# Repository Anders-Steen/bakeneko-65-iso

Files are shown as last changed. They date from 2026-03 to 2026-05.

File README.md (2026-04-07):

## ⚠️ Warning not finished ⚠️
I want to make my own ISO version of the Bakenko 65%.
Make it wireless.
[X] Decide on a ISO layout
[] ~ Replace daughterboard with mcu+interface ~
[X] Update PCB
[] ~ Update case ~ 

# Bakeneko 65 V4 - ISO

A simple 65% keyboard for DIYers. This project is a special homage to TGR x Singa UNIKORN 60 and OTD 356 Mini. See also the [introduction video](https://youtu.be/o677NcIUri4).

## Features

- Single piece tray case
- O-ring gasket mount (Friction fit)
- [Unified Daughterboard](https://github.com/ai03-2725/Unified-Daughterboard)
- ~QMK firmware and VIA~ ZMK
- PCB designed with KiCAD ~5.1.4~ 10.0

## Layout

Bakeneko 65 layouts

## Specs

- Dimensions: 315 x 110 x 30mm
- Front height: 18.5mm
- Home row height: 31mm(with GMK keycaps and bumpons)
- Typing angle: 6 degree
- Weight:
  - PLA Case: 390g
  - Aluminum Case: 760g
- O-ring gasket: VMQ-50(Silicone 50 duro) AS568-264
- MCU: NRF52840

## Notes
- Old files (v1) are no longer available. See [geekhack post](https://geekhack.org/index.php?topic=107316.msg2974824#msg2974824) for the context
- The use of old (v1) mounting posts is prohibited
- All files are to be used at your own risk
- As for stabilizers, only PCB snap ins are supported

## Resources

- Documents: https://drive.google.com/drive/folders/1tddSihOS8Pgf1lTQOjHohYCl8efxXIeH
  - Parts guide and other useful information
  - Will be added and updated as needed
- Discord: https://discord.gg/fMY96TeEwV
  - Have fun with community members
  - Talk about Bakeneko builds and mods, and share your works
  - You can also contact me from there

## Special thanks to

- **Elaine** for [Unikorn](https://geekhack.org/index.php?topic=98587.50). Allowed me to publish the Unikorn-inspired case as open source and encouraged me
- Of course, I also show my respect and gratitude to **yuktsi**
- **coarse** for PCB review and kind support. His great work has refined the PCB well

## Also I should mention

- **OTD** for 356 Mini. Origin of O-ring gasket mount style
- **Evy** for [Plain60 series](https://github.com/evyd13/plain60-c). I used it as a reference for my PCB design. They also answered my miscellaneous questions
- **ai03** for [MX_Alps_Hybrid](https://github.com/ai03-2725/MX_Alps_Hybrid). Also got a lot of help from his discord server
- **overset** for [JP01](https://github.com/overset/JP01). The idea of publishing the case design on Onshape. After seeing their great work I switched from fusion360 to Onshape
- **Rhuk** gave me a lot of advice on keyboard design and manufacturing
- **Maker Keyboards** suggested adding a plate cutout to remove the PCB using a keycap puller
- And many community members for giving me advice and feedback, thanks!

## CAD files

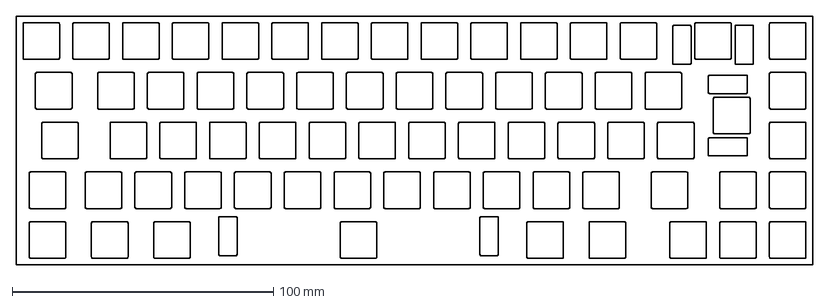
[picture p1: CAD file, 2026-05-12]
plate/fr4/plate-2026-04-13T18_37_32.604Z.dxf
304.8 x 95.2 mm

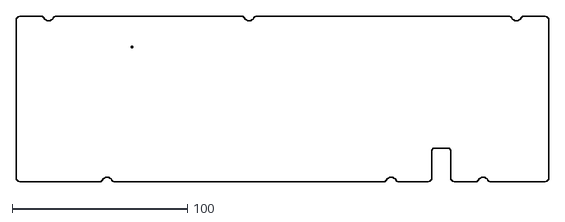
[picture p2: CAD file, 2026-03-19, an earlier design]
pcb_old/pcb-outline.dxf
303.8 x 94.2

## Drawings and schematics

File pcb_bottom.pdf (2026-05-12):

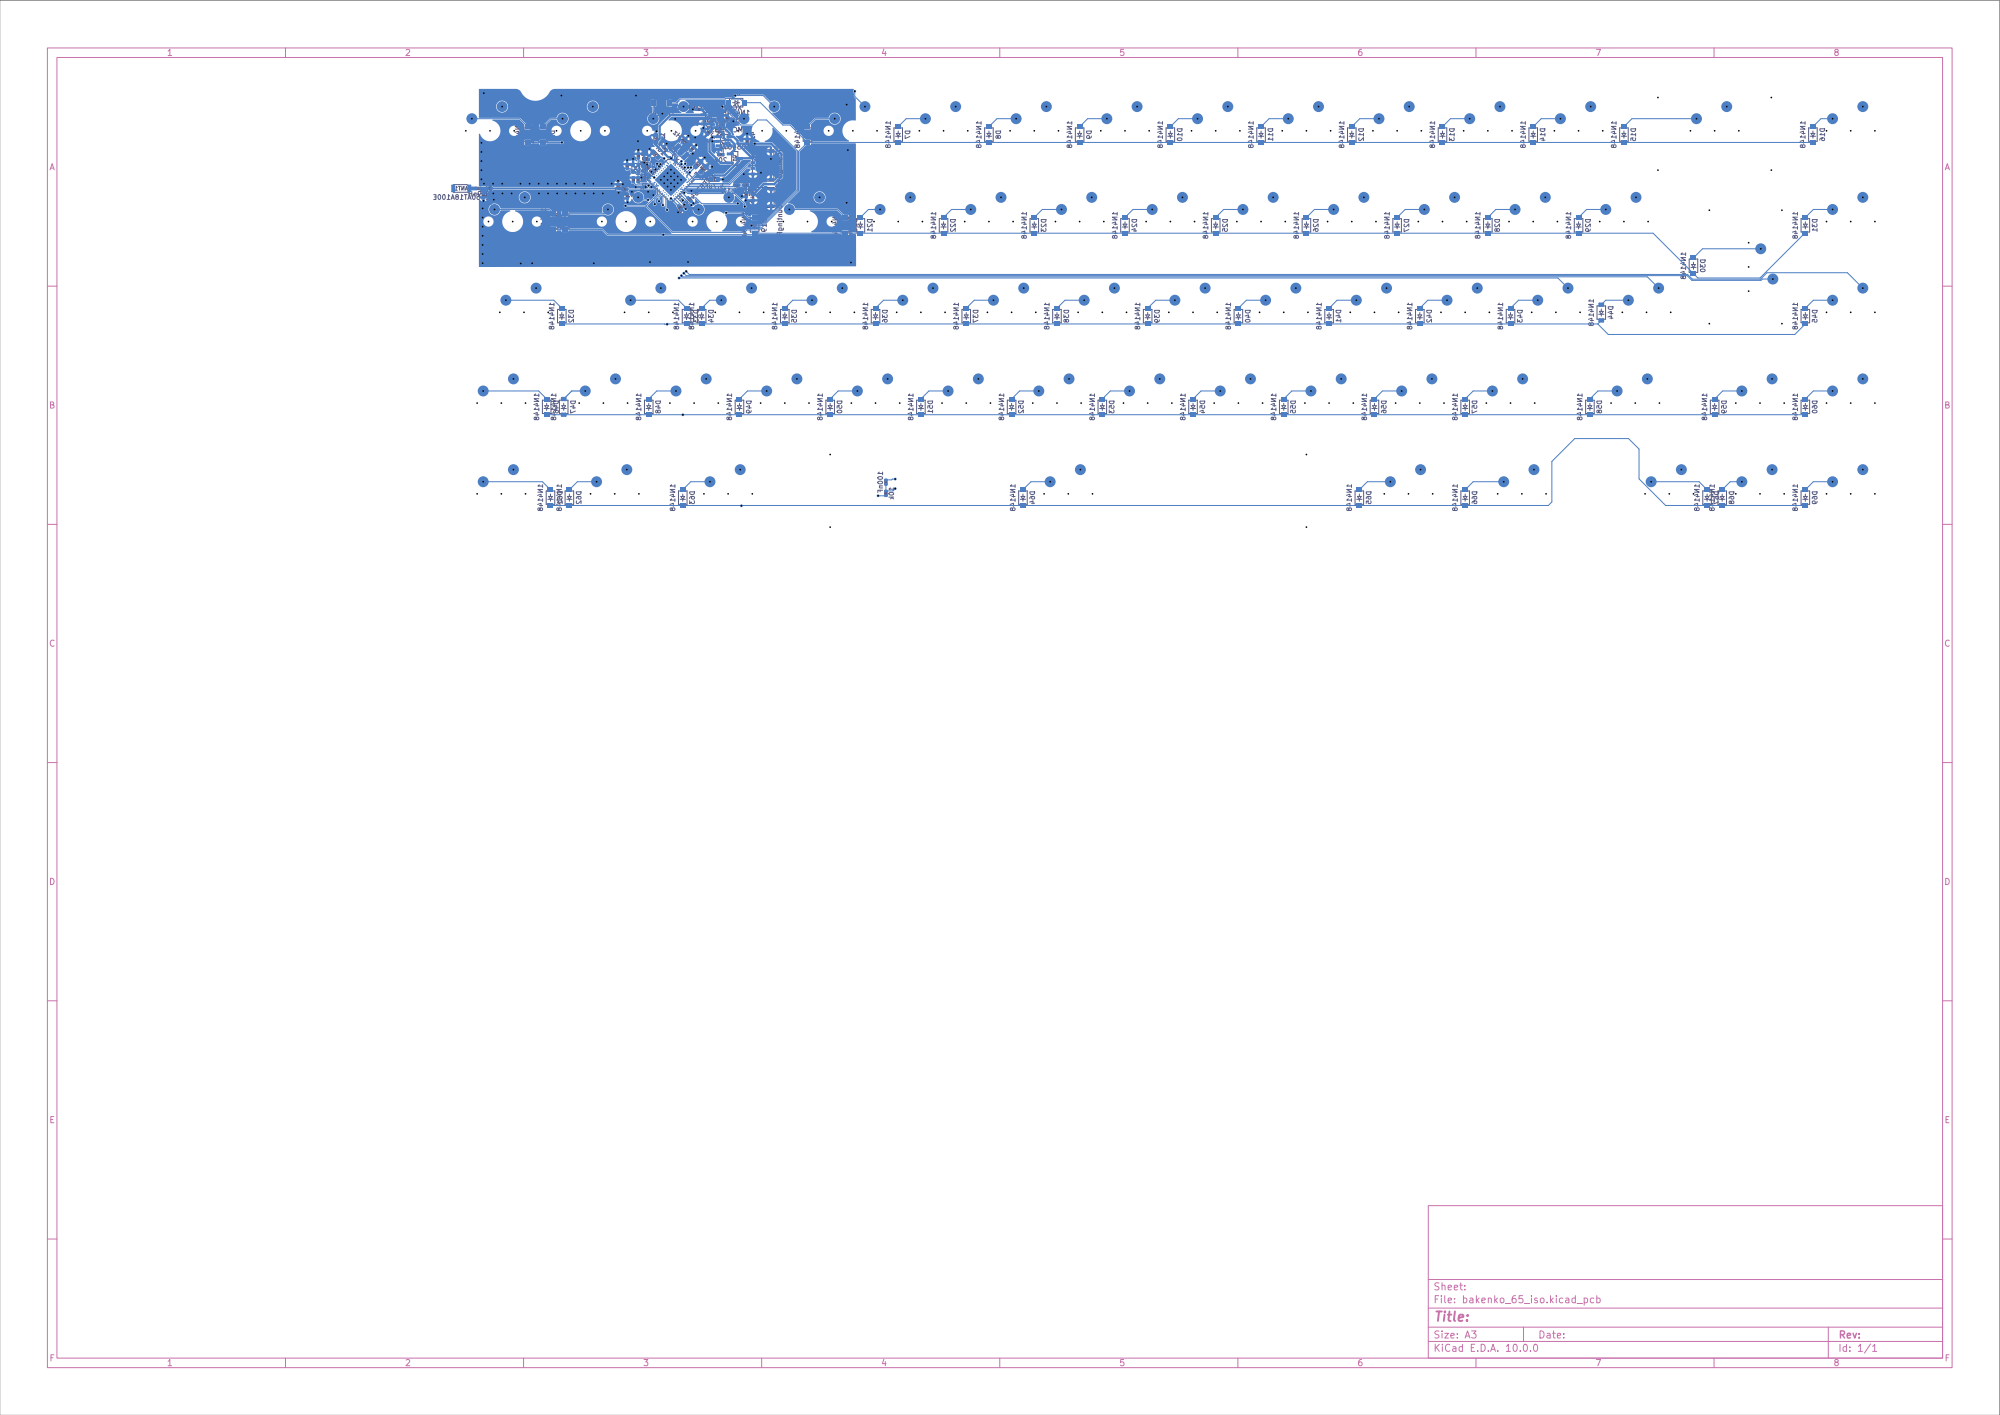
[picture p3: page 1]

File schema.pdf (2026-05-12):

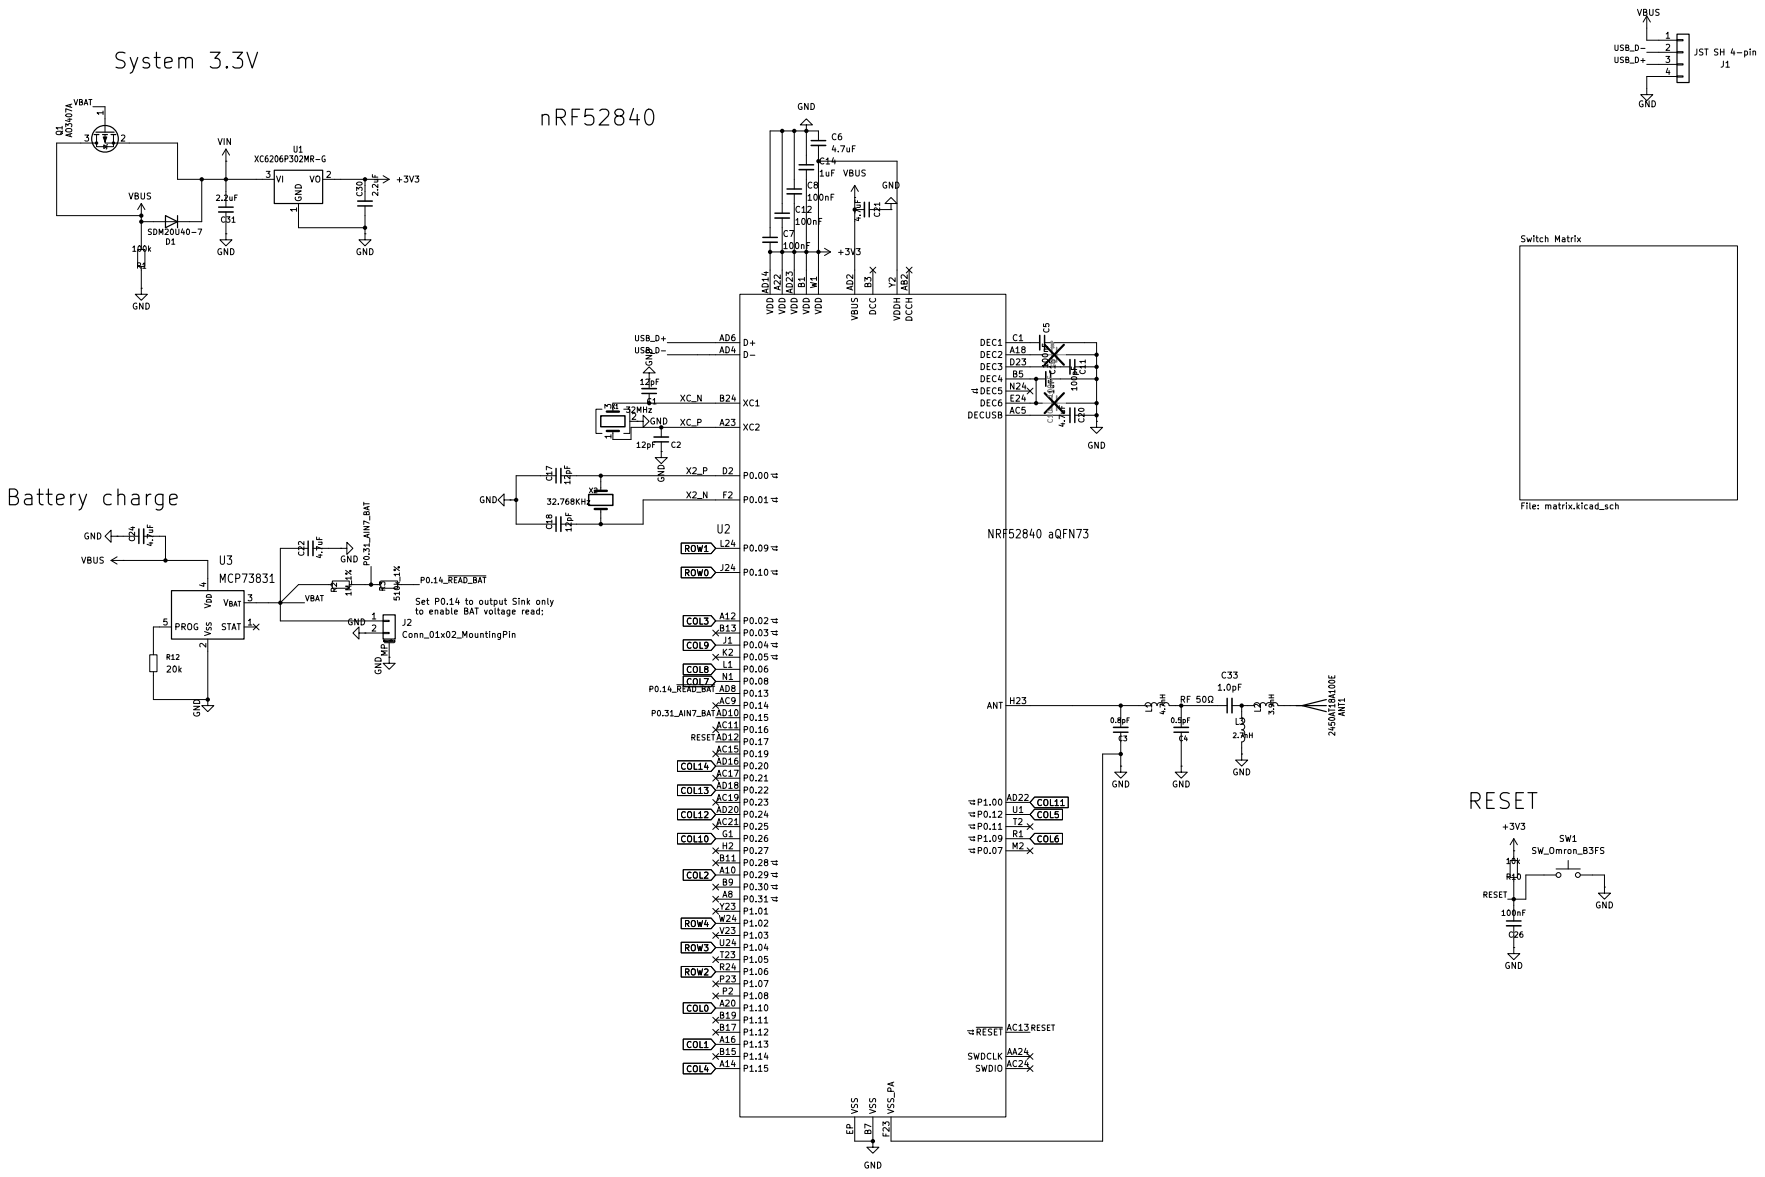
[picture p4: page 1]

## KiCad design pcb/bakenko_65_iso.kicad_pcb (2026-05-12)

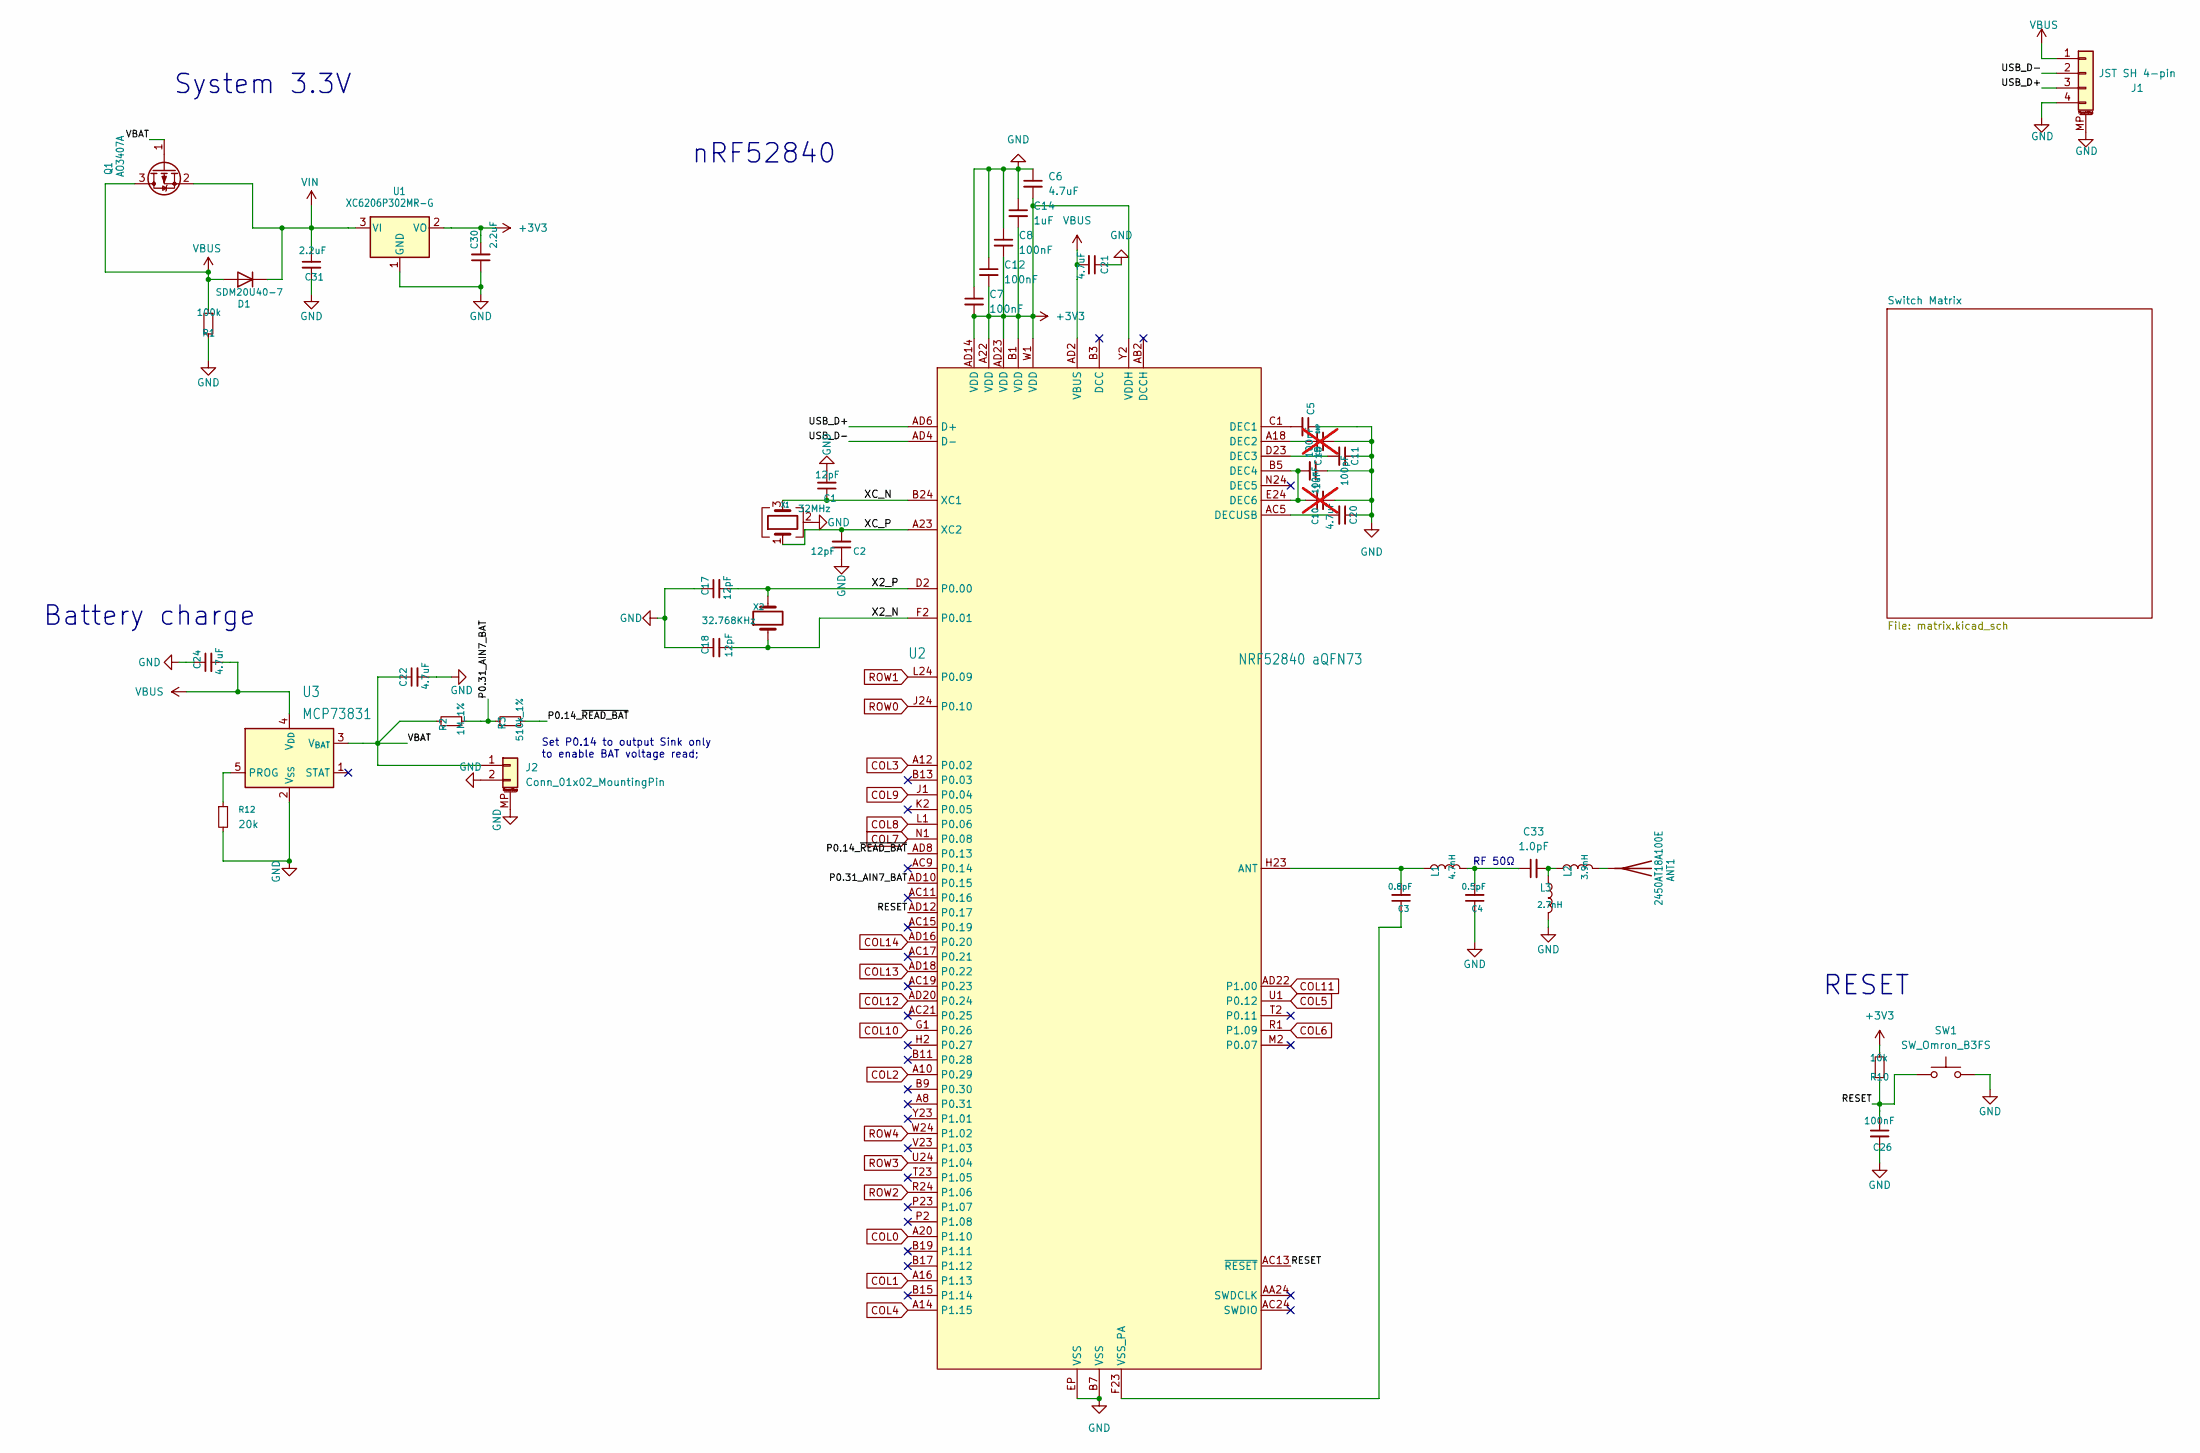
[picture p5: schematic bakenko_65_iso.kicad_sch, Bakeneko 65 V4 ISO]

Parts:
ANT1: 2450AT18A100E; Johanson_2450AT18x100_2400-2500Mhz
C1, C2, C17, C18: 12pF; C_0402_1005Metric
C3: 0.8pF; C_0402_1005Metric
C4: 0.5pF; C_0402_1005Metric
C5, C7, C8, C12, C26: 100nF; C_0402_1005Metric
C6, C20, C21: 4.7uF; C_0603_1608Metric
C10: 100nF; C_0402_1005Metric; not fitted
C11: 100pF; C_0402_1005Metric
C13: DNP; C_0402_1005Metric; not fitted
C14, C15: 1uF; C_0603_1608Metric
C22, C24: 4.7uF; C_0402_1005Metric
C30, C31: 2.2uF; C_0402_1005Metric
C33: 1.0pF; C_0402_1005Metric
D1: SDM20U40-7; D_SOD-523
J1: JST SH 4-pin; Molex_Pico-EZmate_78171-0004_1x04-1MP_P1.20mm_Vertical; LCSC Part # C160404
J2: Conn_01x02_MountingPin; Molex_Pico-EZmate_78171-0002_1x02-1MP_P1.20mm_Vertical
L1: 4.7nH; L_0402_1005Metric
L2: 3.9nH; L_0402_1005Metric
L3: 2.7nH; L_0402_1005Metric
Q1: AO3407A; SOT-23
R1: 100k; R_0402_1005Metric
R2: 1M_1%; R_0402_1005Metric
R3: 510k_1%; R_0402_1005Metric
R10: 10k; R_0402_1005Metric
R12: 20k; R_0402_1005Metric
SW1: SW_Omron_B3FS; SW_SPST_TS-1088-xR020
U1: XC6206P302MR-G; SOT-23
U2: NRF52840 aQFN73; Nordic_AQFN-73-1EP_7x7mm_P0.5mm
U3: MCP73831; SOT-23-5; MPN BQ25101YFPT
X1: 32MHz; Crystal_SMD_2016-4Pin_2.0x1.6mm
X2: 32.768KHz; Crystal_SMD_3215-2Pin_3.2x1.5mm

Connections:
+3V3: C6.2, C7.2, C8.2, C12.2, C14.2, C30.2, R10.2, U1.2 (VO), U2.A22 (VDD), U2.AD14 (VDD), U2.AD23 (VDD), U2.B1 (VDD), U2.W1 (VDD), U2.Y2 (VDDH)
/P0.14_~READ_BAT: R3.2, U2.AD8 (P0.13)
/P0.31_AIN7_BAT: R2.2, R3.1, U2.AD10 (P0.15)
/RESET: C26.1, R10.1, SW1.1, U2.AC13 (~RESET), U2.AD12 (P0.17)
/USB_D+: J1.3, U2.AD6 (D+)
/USB_D-: J1.2, U2.AD4 (D-)
/VBAT: C22.1, J2.1, Q1.1 (G), R2.1, U3.3 (V_{BAT})
/X2_N: C18.2, U2.F2 (P0.01), X2.1
/X2_P: C17.2, U2.D2 (P0.00), X2.2
/XC_N: C1.1, U2.B24 (XC1), X1.3
/XC_P: C2.2, U2.A23 (XC2), X1.1
COL0: U2.A20 (P1.10); also elsewhere on the board
COL1: U2.A16 (P1.13); also elsewhere on the board
COL2: U2.A10 (P0.29); also elsewhere on the board
COL3: U2.A12 (P0.02); also elsewhere on the board
COL4: U2.A14 (P1.15); also elsewhere on the board
COL5: U2.U1 (P0.12); also elsewhere on the board
COL6: U2.R1 (P1.09); also elsewhere on the board
COL7: U2.N1 (P0.08); also elsewhere on the board
COL8: U2.L1 (P0.06); also elsewhere on the board
COL9: U2.J1 (P0.04); also elsewhere on the board
COL10: U2.G1 (P0.26); also elsewhere on the board
COL11: U2.AD22 (P1.00); also elsewhere on the board
COL12: U2.AD20 (P0.24); also elsewhere on the board
COL13: U2.AD18 (P0.22); also elsewhere on the board
COL14: U2.AD16 (P0.20); also elsewhere on the board
GND: C1.2, C2.1, C4.1, C5.1, C6.1, C7.1, C8.1, C10.2, C11.1, C12.1, C13.2, C14.1, C15.1, C17.1, C18.1, C20.1, C21.1, C22.2, C24.1, C26.2, C30.1, C31.2, J1.4, J1.MP (MountPin), J2.2, J2.MP (MountPin), L3.2, R1.2, R12.2, SW1.2, U1.1 (GND), U2.B7 (VSS), U2.EP (VSS), U3.2 (V_{SS}), X1.2 (G), X1.4 (G)
unnamed: ANT1.1 (A_1), L2.2
unnamed: C4.2, C33.1, L1.2
unnamed: C33.2, L2.1, L3.1
unnamed: C3.2, L1.1, U2.H23 (ANT)
unnamed: C5.2, U2.C1 (DEC1)
unnamed: C13.1, U2.A18 (DEC2)
unnamed: C11.2, U2.D23 (DEC3)
unnamed: C10.1, C15.2, U2.B5 (DEC4), U2.E24 (DEC6)
unnamed: C20.2, U2.AC5 (DECUSB)
unnamed: C3.1, U2.F23 (VSS_PA)
unnamed: R12.1, U3.5 (PROG)
ROW0: U2.J24 (P0.10); also elsewhere on the board
ROW1: U2.L24 (P0.09); also elsewhere on the board
ROW2: U2.R24 (P1.06); also elsewhere on the board
ROW3: U2.U24 (P1.04); also elsewhere on the board
ROW4: U2.W24 (P1.02); also elsewhere on the board
VBUS: C21.2, C24.2, D1.2 (A), J1.1, Q1.3 (D), R1.1, U2.AD2 (VBUS), U3.4 (V_{DD})
VIN: C31.1, D1.1 (K), Q1.2 (S), U1.3 (VI)

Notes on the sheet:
nRF52840
Battery charge
System 3.3V
RESET
RF 50Ω
Set P0.14 to output Sink only to enable BAT voltage read;

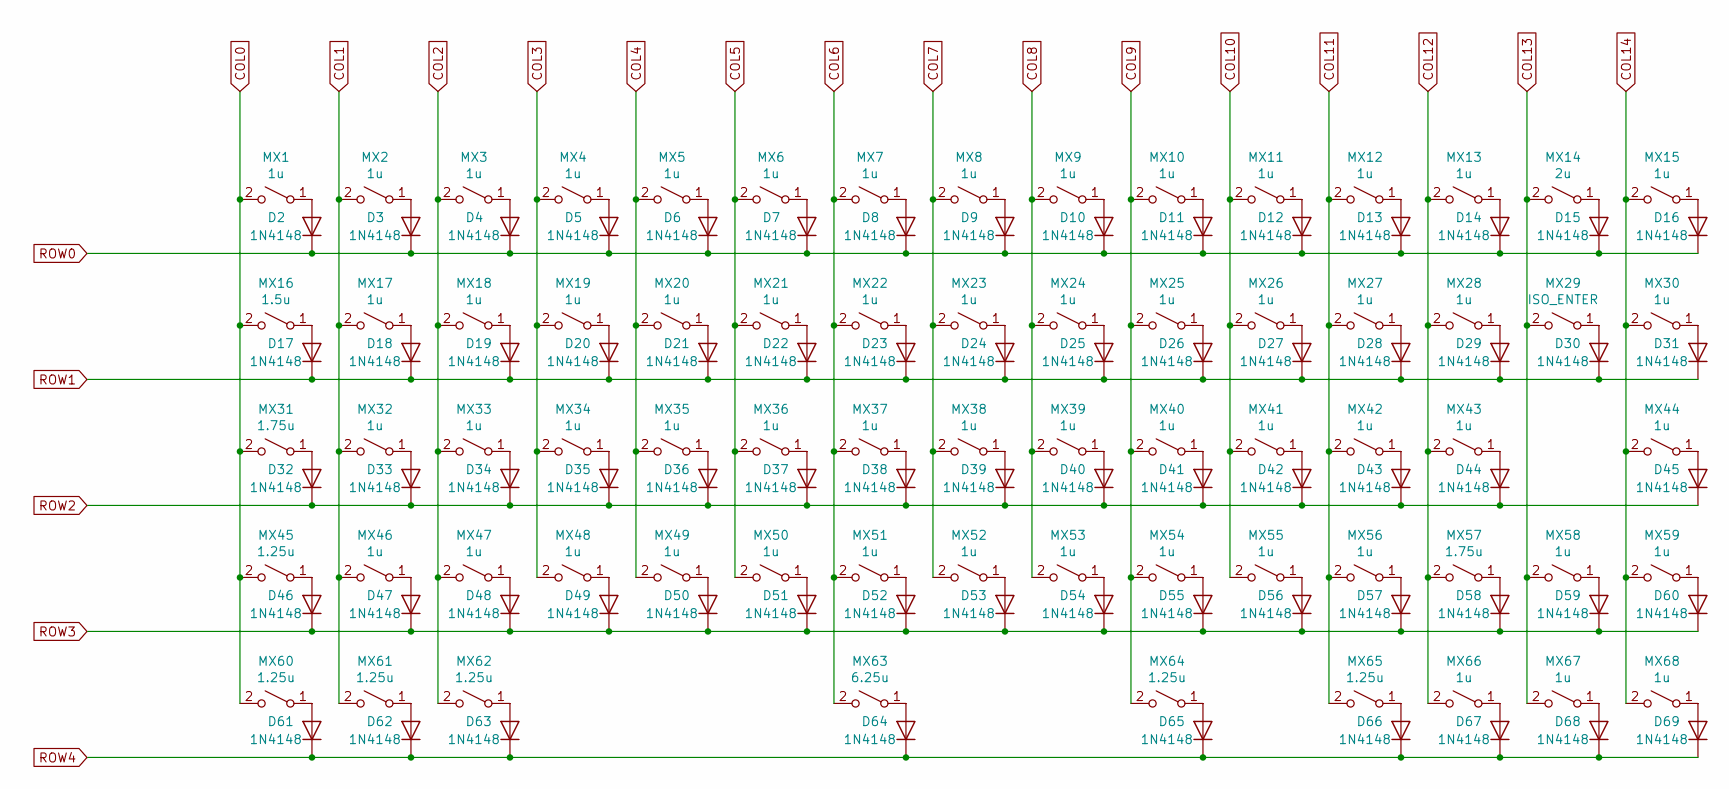
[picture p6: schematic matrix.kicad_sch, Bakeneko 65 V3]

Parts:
D2, D3, D4, D5, D6, D7, D8, D9, D10, D11, D12, D13, D14, D15, D16, D17, D18, D19, D20, D21, D22, D23, D24, D25, D26, D27, D28, D29, D30, D31, D32, D33, D34, D35, D36, D37, D38, D39, D40, D41, D42, D43, D44, D45, D46, D47, D48, D49, D50, D51, D52, D53, D54, D55, D56, D57, D58, D59, D60, D61, D62, D63, D64, D65, D66, D67, D68, D69: 1N4148; D_SOD-123; LCSC Part # C81598
MX1, MX2, MX3, MX4, MX5, MX6, MX7, MX8, MX9, MX10, MX11, MX12, MX13, MX15, MX17, MX18, MX19, MX20, MX21, MX22, MX23, MX24, MX25, MX26, MX27, MX28, MX30, MX32, MX33, MX34, MX35, MX36, MX37, MX38, MX39, MX40, MX41, MX42, MX43, MX44, MX46, MX47, MX48, MX49, MX50, MX51, MX52, MX53, MX54, MX55, MX56, MX58, MX59, MX66, MX67, MX68: 1u; SW_MX_1u
MX14: 2u; SW_MX_1u
MX16: 1.5u; SW_MX_1.5u
MX29: ISO_ENTER; SW_MX_1u
MX31, MX57: 1.75u; SW_MX_1.75u
MX45, MX60, MX61, MX62, MX64, MX65: 1.25u; SW_MX_1.25u
MX63: 6.25u; SW_MX_1u

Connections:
COL0: MX1.2 (B), MX16.2 (B), MX31.2 (B), MX45.2 (B), MX60.2 (B); also elsewhere on the board
COL1: MX2.2 (B), MX17.2 (B), MX32.2 (B), MX46.2 (B), MX61.2 (B); also elsewhere on the board
COL2: MX3.2 (B), MX18.2 (B), MX33.2 (B), MX47.2 (B), MX62.2 (B); also elsewhere on the board
COL3: MX4.2 (B), MX19.2 (B), MX34.2 (B), MX48.2 (B); also elsewhere on the board
COL4: MX5.2 (B), MX20.2 (B), MX35.2 (B), MX49.2 (B); also elsewhere on the board
COL5: MX6.2 (B), MX21.2 (B), MX36.2 (B), MX50.2 (B); also elsewhere on the board
COL6: MX7.2 (B), MX22.2 (B), MX37.2 (B), MX51.2 (B), MX63.2 (B); also elsewhere on the board
COL7: MX8.2 (B), MX23.2 (B), MX38.2 (B), MX52.2 (B); also elsewhere on the board
COL8: MX9.2 (B), MX24.2 (B), MX39.2 (B), MX53.2 (B); also elsewhere on the board
COL9: MX10.2 (B), MX25.2 (B), MX40.2 (B), MX54.2 (B), MX64.2 (B); also elsewhere on the board
COL10: MX11.2 (B), MX26.2 (B), MX41.2 (B), MX55.2 (B); also elsewhere on the board
COL11: MX12.2 (B), MX27.2 (B), MX42.2 (B), MX56.2 (B), MX65.2 (B); also elsewhere on the board
COL12: MX13.2 (B), MX28.2 (B), MX43.2 (B), MX57.2 (B), MX66.2 (B); also elsewhere on the board
COL13: MX14.2 (B), MX29.2 (B), MX58.2 (B), MX67.2 (B); also elsewhere on the board
COL14: MX15.2 (B), MX30.2 (B), MX44.2 (B), MX59.2 (B), MX68.2 (B); also elsewhere on the board
unnamed: D2.2 (A), MX1.1 (A)
unnamed: D3.2 (A), MX2.1 (A)
unnamed: D4.2 (A), MX3.1 (A)
unnamed: D5.2 (A), MX4.1 (A)
unnamed: D6.2 (A), MX5.1 (A)
unnamed: D7.2 (A), MX6.1 (A)
unnamed: D8.2 (A), MX7.1 (A)
unnamed: D9.2 (A), MX8.1 (A)
unnamed: D10.2 (A), MX9.1 (A)
unnamed: D11.2 (A), MX10.1 (A)
unnamed: D12.2 (A), MX11.1 (A)
unnamed: D13.2 (A), MX12.1 (A)
unnamed: D14.2 (A), MX13.1 (A)
unnamed: D15.2 (A), MX14.1 (A)
unnamed: D16.2 (A), MX15.1 (A)
unnamed: D17.2 (A), MX16.1 (A)
unnamed: D18.2 (A), MX17.1 (A)
unnamed: D19.2 (A), MX18.1 (A)
unnamed: D20.2 (A), MX19.1 (A)
unnamed: D21.2 (A), MX20.1 (A)
unnamed: D22.2 (A), MX21.1 (A)
unnamed: D23.2 (A), MX22.1 (A)
unnamed: D24.2 (A), MX23.1 (A)
unnamed: D25.2 (A), MX24.1 (A)
unnamed: D26.2 (A), MX25.1 (A)
unnamed: D27.2 (A), MX26.1 (A)
unnamed: D28.2 (A), MX27.1 (A)
unnamed: D29.2 (A), MX28.1 (A)
unnamed: D30.2 (A), MX29.1 (A)
unnamed: D31.2 (A), MX30.1 (A)
unnamed: D32.2 (A), MX31.1 (A)
unnamed: D33.2 (A), MX32.1 (A)
unnamed: D34.2 (A), MX33.1 (A)
unnamed: D35.2 (A), MX34.1 (A)
unnamed: D36.2 (A), MX35.1 (A)
unnamed: D37.2 (A), MX36.1 (A)
unnamed: D38.2 (A), MX37.1 (A)
unnamed: D39.2 (A), MX38.1 (A)
unnamed: D40.2 (A), MX39.1 (A)
unnamed: D41.2 (A), MX40.1 (A)
unnamed: D42.2 (A), MX41.1 (A)
unnamed: D43.2 (A), MX42.1 (A)
unnamed: D44.2 (A), MX43.1 (A)
unnamed: D45.2 (A), MX44.1 (A)
unnamed: D46.2 (A), MX45.1 (A)
unnamed: D47.2 (A), MX46.1 (A)
unnamed: D48.2 (A), MX47.1 (A)
unnamed: D49.2 (A), MX48.1 (A)
unnamed: D50.2 (A), MX49.1 (A)
unnamed: D51.2 (A), MX50.1 (A)
unnamed: D52.2 (A), MX51.1 (A)
unnamed: D53.2 (A), MX52.1 (A)
unnamed: D54.2 (A), MX53.1 (A)
unnamed: D55.2 (A), MX54.1 (A)
unnamed: D56.2 (A), MX55.1 (A)
unnamed: D57.2 (A), MX56.1 (A)
unnamed: D58.2 (A), MX57.1 (A)
unnamed: D59.2 (A), MX58.1 (A)
unnamed: D60.2 (A), MX59.1 (A)
unnamed: D61.2 (A), MX60.1 (A)
unnamed: D62.2 (A), MX61.1 (A)
unnamed: D63.2 (A), MX62.1 (A)
unnamed: D64.2 (A), MX63.1 (A)
unnamed: D65.2 (A), MX64.1 (A)
unnamed: D66.2 (A), MX65.1 (A)
unnamed: D67.2 (A), MX66.1 (A)
unnamed: D68.2 (A), MX67.1 (A)
unnamed: D69.2 (A), MX68.1 (A)
ROW0: D2.1 (K), D3.1 (K), D4.1 (K), D5.1 (K), D6.1 (K), D7.1 (K), D8.1 (K), D9.1 (K), D10.1 (K), D11.1 (K), D12.1 (K), D13.1 (K), D14.1 (K), D15.1 (K), D16.1 (K); also elsewhere on the board
ROW1: D17.1 (K), D18.1 (K), D19.1 (K), D20.1 (K), D21.1 (K), D22.1 (K), D23.1 (K), D24.1 (K), D25.1 (K), D26.1 (K), D27.1 (K), D28.1 (K), D29.1 (K), D30.1 (K), D31.1 (K); also elsewhere on the board
ROW2: D32.1 (K), D33.1 (K), D34.1 (K), D35.1 (K), D36.1 (K), D37.1 (K), D38.1 (K), D39.1 (K), D40.1 (K), D41.1 (K), D42.1 (K), D43.1 (K), D44.1 (K), D45.1 (K); also elsewhere on the board
ROW3: D46.1 (K), D47.1 (K), D48.1 (K), D49.1 (K), D50.1 (K), D51.1 (K), D52.1 (K), D53.1 (K), D54.1 (K), D55.1 (K), D56.1 (K), D57.1 (K), D58.1 (K), D59.1 (K), D60.1 (K); also elsewhere on the board
ROW4: D61.1 (K), D62.1 (K), D63.1 (K), D64.1 (K), D65.1 (K), D66.1 (K), D67.1 (K), D68.1 (K), D69.1 (K); also elsewhere on the board

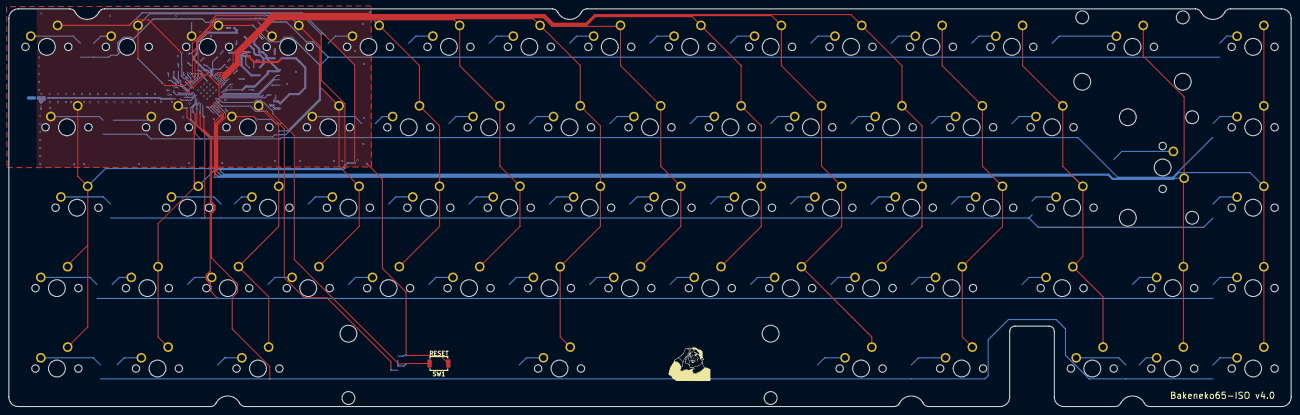
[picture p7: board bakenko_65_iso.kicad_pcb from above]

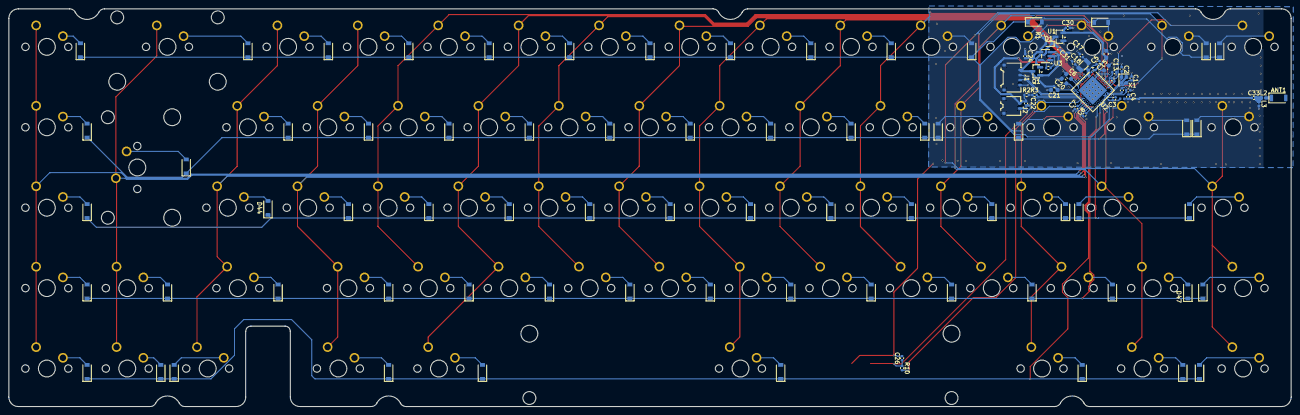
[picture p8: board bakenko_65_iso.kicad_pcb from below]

Board: 2 copper layers, 303.8 x 94.2 mm, 179 parts (110 on the bottom side), 113 nets.

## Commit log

2026-02-19 Removed ANSI production files
    [bakeneko-65-pcb-v3-jlcpcb-bom.csv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]
2026-04-06 WIP + Cleaned repository
    [bakeneko-65-pcb.kicad_pcb, bakeneko-65-pcb.sch, bakenko_65_iso.kicad_pcb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]
2026-04-07 🧹Cleaned more up and updated the readme
    [bakenko_65_iso.kicad_pcb, bakenko_65_iso.kicad_sch, bakenko_65_iso.sch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]
2026-04-08 Cleaning zones and moving antenna
    [bakenko_65_iso.kicad_pcb]
2026-04-09 Connecting reset and reducing errors and warnings
    [bakenko_65_iso.kicad_pcb, bakenko_65_iso.kicad_sch]
2026-04-13 Adding changes thanks to comment from devzone nordic
    [bakenko_65_iso.kicad_pcb, bakenko_65_iso.kicad_sch]
2026-05-12 Final changes before pcb-assebly
    [bakeneko-65-fr4-plate.kicad_pcb, bakeneko-65-fr4-plate.sch, bakeneko-65-plate.dxf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]

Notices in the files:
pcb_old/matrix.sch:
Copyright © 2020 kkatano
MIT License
